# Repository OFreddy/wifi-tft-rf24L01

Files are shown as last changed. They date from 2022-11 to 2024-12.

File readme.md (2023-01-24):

# WifiDisplay

A project for communicating with Hoymiles solar inverters combined with the option to display different values on a 2.4 inch TFT display. 

## Preface
Inspired from the [discussion](https://www.mikrocontroller.net/topic/525778) on (Mikrocontroller.net) I also started investigating on protocol and communication details. With [this](https://www.mikrocontroller.net/topic/525778?page=single#7014857)
 post a first contact to the inverters was the base for several projects.
I wanted an independent display to always have an overview of the current yield data in a simple and clear manner.

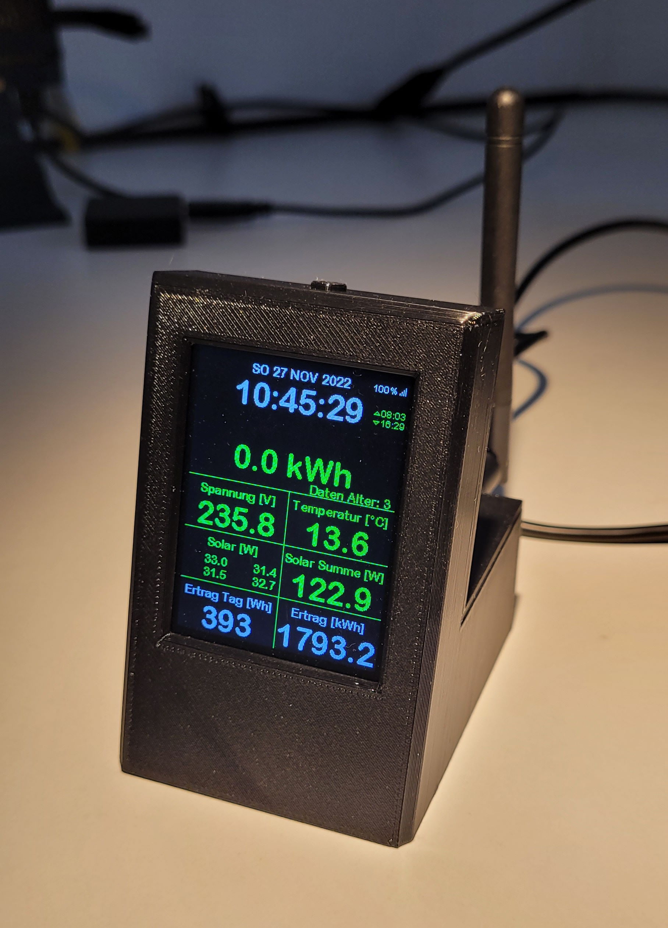
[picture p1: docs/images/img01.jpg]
wifidisplay
   

This project is still a work in progress. It is far away from the almost perfect and comfortable and easy to use solutions from other projects. 

Some more pictures of the latest prototype can be found [here](docs/images/README.md).
---
## Firmware

The firmware for the EPS8266 microcontroller is build with Arduino PlatformIO Framework for the ESP8266. 

It uses a snapshot or a fork of the following projects:

- [ThingPulse minigrafx](https://github.com/ThingPulse/minigrafx)
- [Bounce2](https://github.com/thomasfredericks/Bounce2)
- [RobTillaart CRC](https://github.com/RobTillaart/CRC)
- [BuelowP sunset](https://github.com/buelowp/sunset)

and some more (experimental)...

---
## Hardware - Required components and material 

### ESP8266 WeMos D1 mini

As controller platform a WeMos D1 mini compatible ESP8266 board is required.

Sample picture

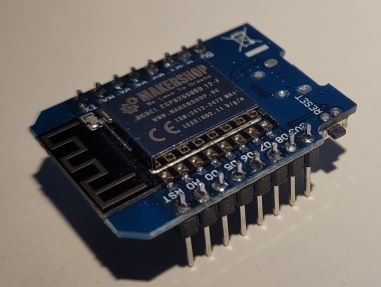
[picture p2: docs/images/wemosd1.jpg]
WeMos-D1 mini


Source of supply
[Makershop](https://www.makershop.de/plattformen/d1-mini/esp8266-mini-board/)
[AZ-Delivery](https://www.az-delivery.de/products/d1-mini)

### NRF24L01+ radio board with external antenna

Sample picture

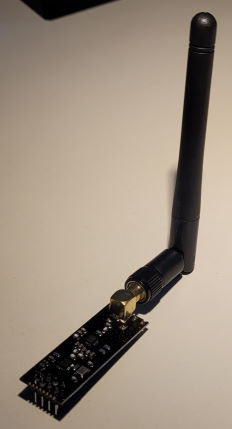
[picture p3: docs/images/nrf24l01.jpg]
NRF24l01


### ILI9341 based TFT Display 320x240 pixel

I always order the TFT modules directly from China via AliExpress. As the suppliers change frequently it is difficult to keep a link updated here. Make sure the pcb has the dimensions 77mm x 42.5mm and a 14 pin header at the bottom for target connection.

**Sample picture**
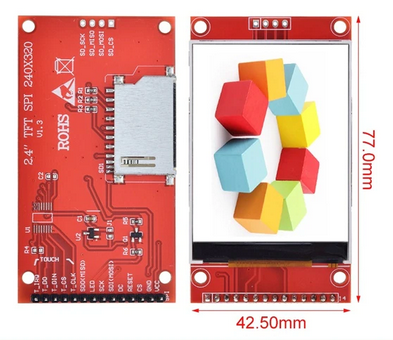
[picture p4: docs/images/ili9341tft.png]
ILI9341 based TFT display


### BOM for the pcb
|Quantity|Item|
|---|----|
|2 pc.|socket strip 8x1 pin 6mm heigth 2.56mm pitch|
|1 pc.|socket strip 4x2 pin 2.56mm pitch|
|1 pc.|socket strip 8x1 pin 8mm height 2.56mm pitch|
|1 pc.|pin header 2x1 pin 2.56mm pitch|
|1 pc.|Polarized capacitor 100uF 35V 2.56mm pitch|
|1 pc.|Capacitor SMD 100nF 0603|
|1 pc.|Resistor SMD 10k 0603|
|1 pc.|Resistor SMD 1k 0603|

### Other components and mounting material

**A tact Button Switch 6 x 6 x 4.3 mm**

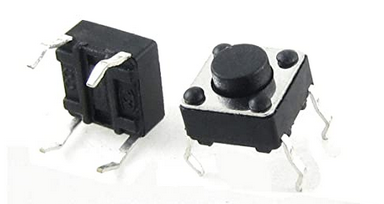
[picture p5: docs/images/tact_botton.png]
Tact botton switch


The switch is used for different options when interacting with the display application. It is mounted inside the housing using the 3D printed mount. The pins of the switch must be bent straight and put through the small holes in the holder as shown on this picture.

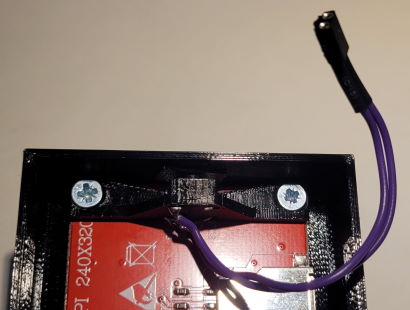
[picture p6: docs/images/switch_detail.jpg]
switch


|Quantity|Item|
|---|----|
|4 pc.|Countersunk screw M3 x 5mm|
|6 pc.|Washer 3.2mm|
|4 pc.|Cylinder head screw M3 x 8mm|
|4 pc.|Nuts M3|

---
## Further documentation

### Connection Summary for ILI9341 TFT Display:

ESP8266       -> ILI9341
Vin           -> Vcc        (red)
GND           -> GND        (black)
GPIO 15  (D8) -> CS         (violett)
GPIO 2   (D4) -> RESET      (brown)
GPIO 4   (D2) -> D/C        (gray)
GPIO 13  (D7) -> SDI(MOSI)  (green)
GPIO 14  (D5) -> SCK        (yellow)
GPIO 5   (D1) -> LED        (orange)
GPIO 12  (D6) -> SDO(MISO)  (spare)

---
## Related Projects
- [OpenDTU](https://github.com/tbnobody/OpenDTU)
- [Ahoy](https://github.com/grindylow/ahoy)
- [DTU Simulator](https://github.com/Ziyatoe/DTUsimMI1x00-Hoymiles)
- [OpenDTU extended to talk to Victrons MPPT battery chargers (Ve.Direct)](https://github.com/helgeerbe/OpenDTU_VeDirect)
- [BreakoutBoard - sample printed circuit board for OpenDTU and Ahoy](https://github.com/dokuhn/openDTU-BreakoutBoard)

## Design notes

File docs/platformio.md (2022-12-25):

# PlatformIO

## Generic boards

Default boards definitionen sind in:
C:\Users\Oliver\.platformio\platforms\espressif8266\boards

Board definition in separates Verzeichnis. Referenzierung dann in Platforio.ini

'board      = esp8266_4M2M'

In der entdprechenden Board.json findet sich der Eintrag:

'"variant": "d1_mini"'

Die Variante referenziert dann die Einstellungen aus:
C:\Users\Oliver\.platformio\packages\framework-arduinoespressif8266\variants

z.B. pins_arduino.h

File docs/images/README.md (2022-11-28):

# Project pictures

Here are some pictures of the project results so far.
***



***

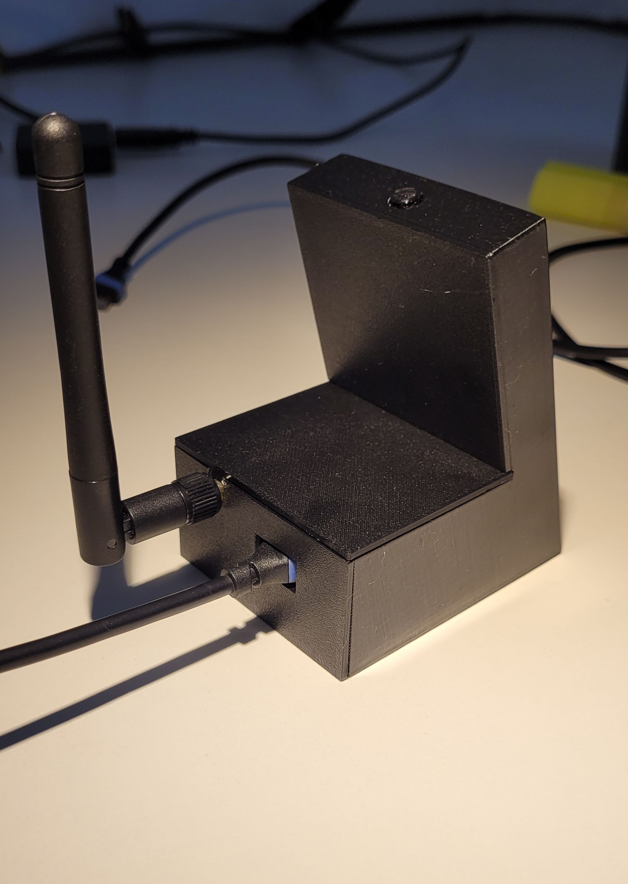
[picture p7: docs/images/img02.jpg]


***

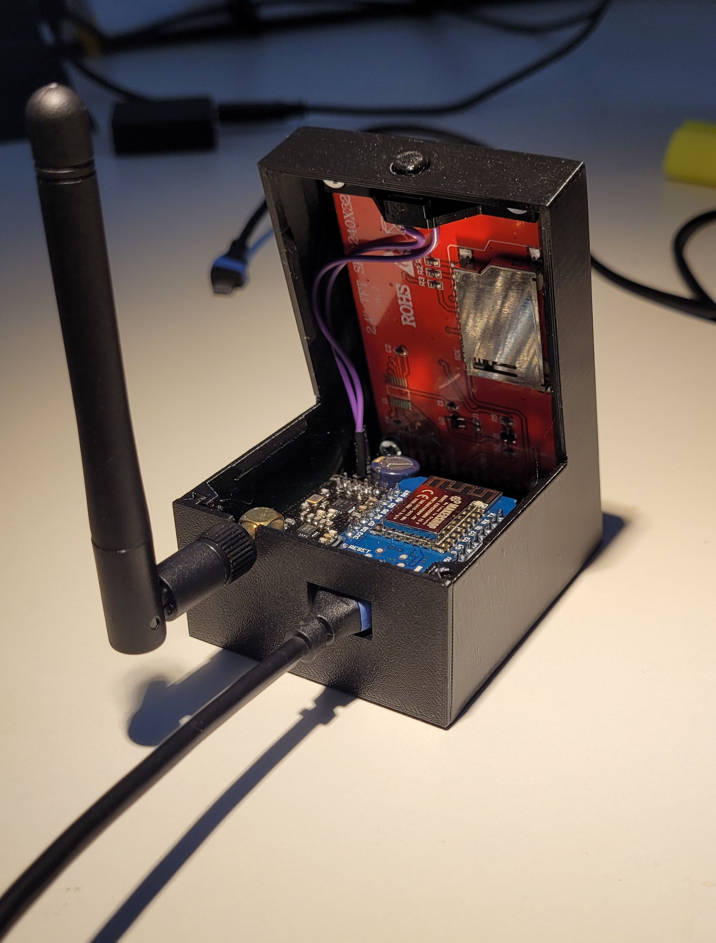
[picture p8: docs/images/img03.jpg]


***

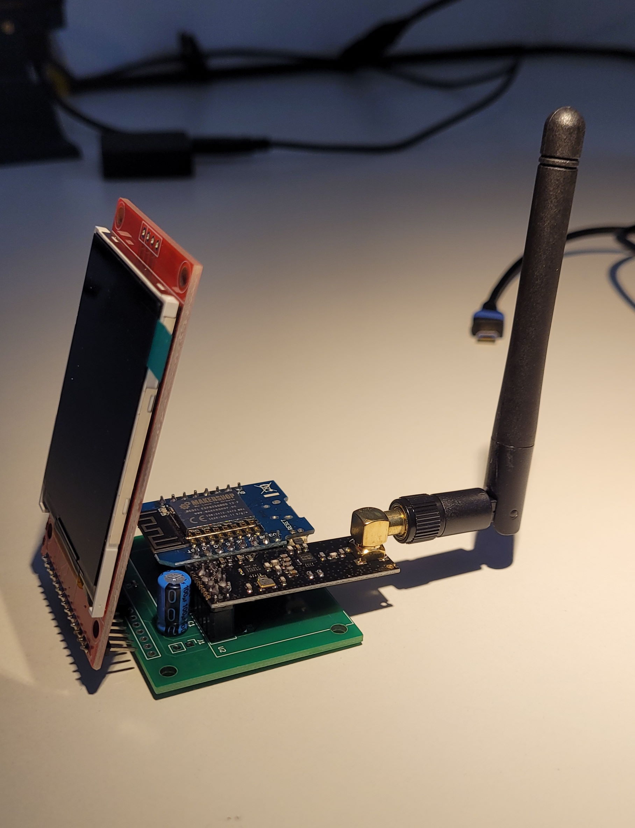
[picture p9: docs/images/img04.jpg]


***

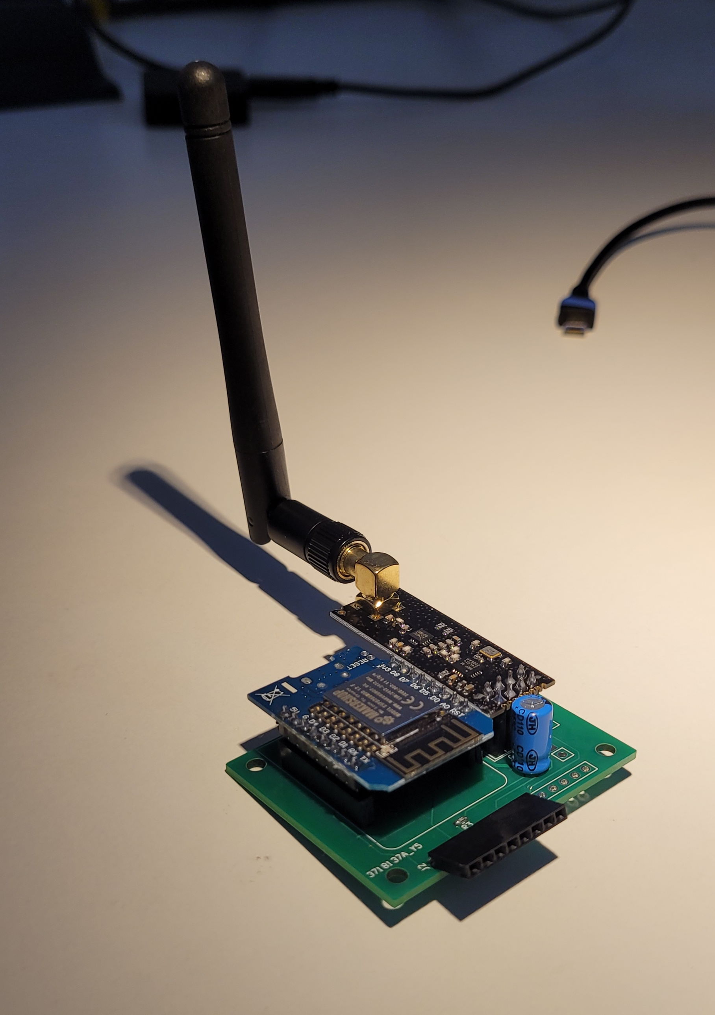
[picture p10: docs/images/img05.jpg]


***

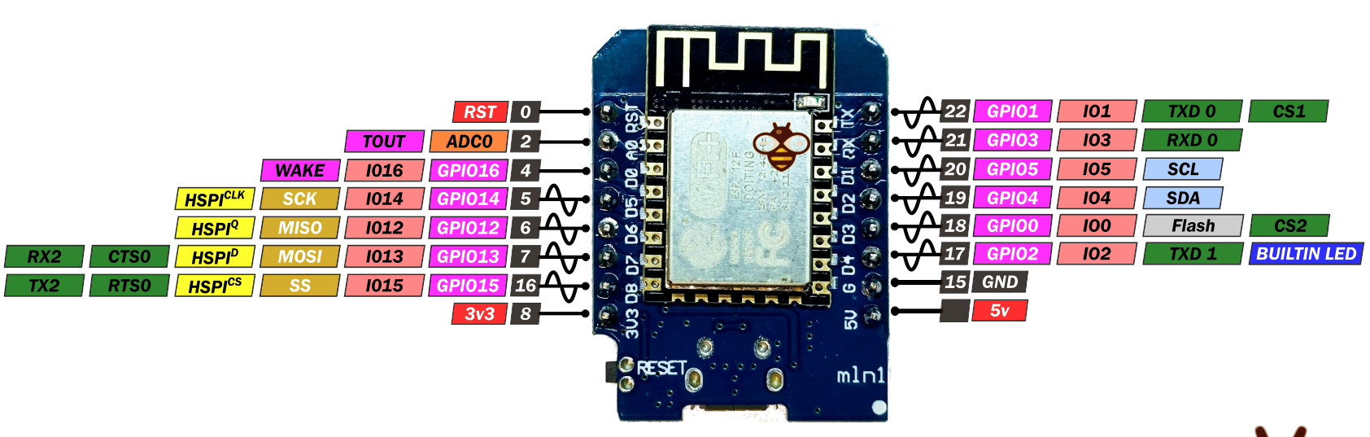
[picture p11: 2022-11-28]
docs/d1_mini_pinout.png

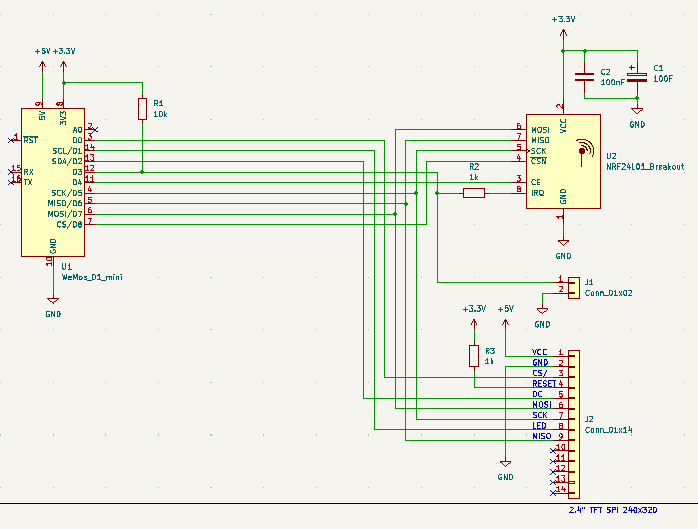
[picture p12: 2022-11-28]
docs/images/schematic.png

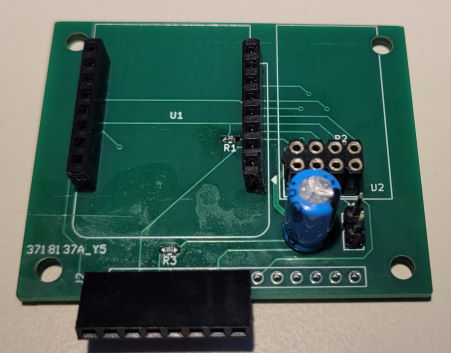
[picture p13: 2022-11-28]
docs/images/pcb_equipped.jpg

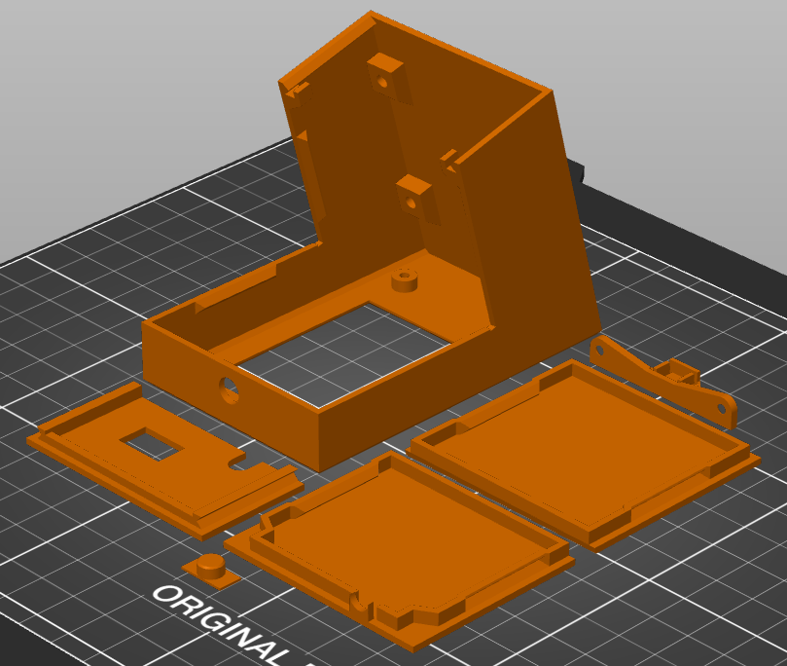
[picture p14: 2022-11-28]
docs/images/prusa slicer project.png

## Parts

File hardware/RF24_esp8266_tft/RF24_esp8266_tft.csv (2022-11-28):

Source: | D:\.workspace\wifidisplay\hardware\RF24_esp8266_tft\RF24_esp8266_tft.kicad_sch
Date: | 27.11.2022 12:58:12
Tool: | Eeschema (6.0.7)
Generator: | C:\Program Files\KiCad\6.0\bin\scripting\plugins/bom_csv_grouped_by_value_with_fp.py
Component Count: | 13
Ref | Qnty | Value | Cmp name | Footprint | Description | Vendor
C1, | 1 | 100uF | C_Polarized | Capacitor_THT:CP_Radial_D5.0mm_P2.50mm | Polarized capacitor
C2, | 1 | 100nF | C | Capacitor_SMD:C_0201_0603Metric_Pad0.64x0.40mm_HandSolder | Unpolarized capacitor
H1, H2, H3, H4, | 4 | MountingHole | MountingHole | MountingHole:MountingHole_3.2mm_M3_DIN965 | Mounting Hole without connection
J1, | 1 | Conn_01x02 | Conn_01x02 | Connector_PinHeader_2.54mm:PinHeader_1x02_P2.54mm_Vertical | Generic connector, single row, 01x02, script generated (kicad-library-utils/schlib/autogen/connector/)
J2, | 1 | Conn_01x14 | Conn_01x14 | Connector_PinHeader_2.54mm:PinHeader_1x14_P2.54mm_Vertical | Generic connector, single row, 01x14, script generated (kicad-library-utils/schlib/autogen/connector/)
R1, | 1 | 10k | R | Resistor_SMD:R_0603_1608Metric_Pad0.98x0.95mm_HandSolder | Resistor
R2, R3, | 2 | 1k | R | Resistor_SMD:R_0603_1608Metric_Pad0.98x0.95mm_HandSolder | Resistor
U1, | 1 | WeMos_D1_mini | WeMos_D1_mini | Module:WEMOS_D1_mini_light | 32-bit microcontroller module with WiFi
U2, | 1 | NRF24L01_Breakout | NRF24L01_Breakout | RF_Module:nRF24L01_Breakout | Ultra low power 2.4GHz RF Transceiver, Carrier PCB

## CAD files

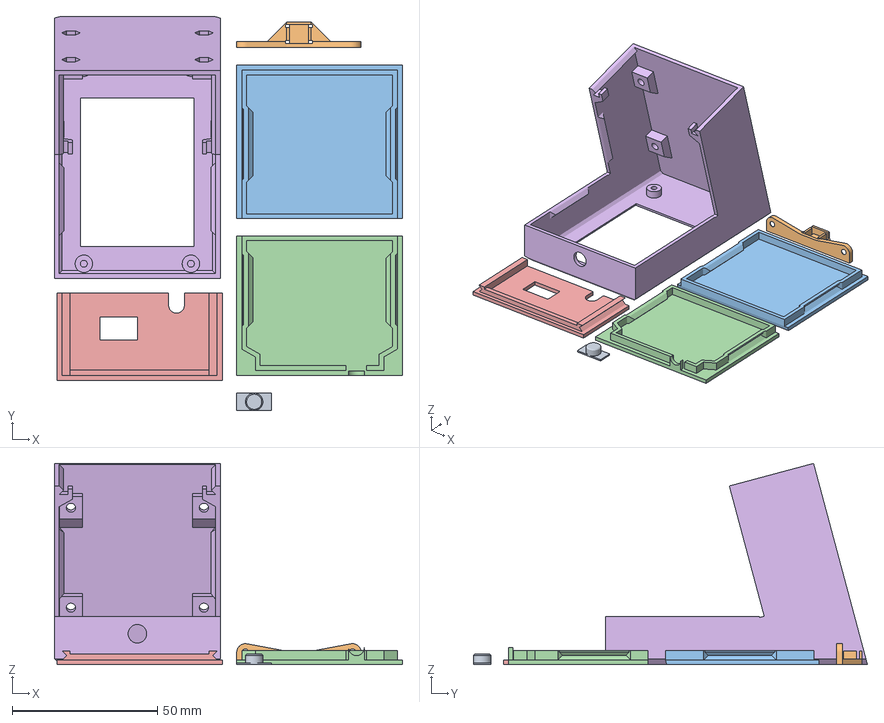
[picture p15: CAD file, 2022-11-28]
hardware/Housing 3d-model/ESP RF2401 TFT Housing complete.3mf
119.6 x 135.4 x 69.2 mm
ESP RF2401 TFT Gehäuse Knopf
ESP RF2401 TFT Gehäuse Taster Halter
ESP RF2401 TFT Gehäuse Deckel
ESP RF2401 TFT Gehäuse hinten oben
ESP RF2401 TFT Gehäuse hinten
ESP RF2401 TFT Gehäuse

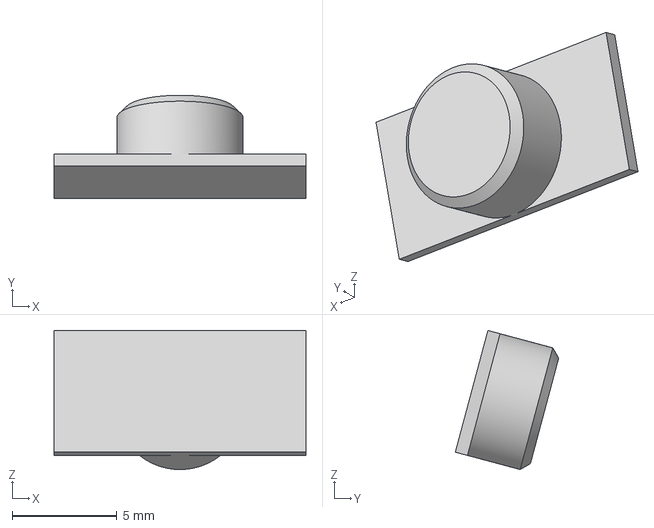
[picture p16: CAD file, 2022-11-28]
hardware/Housing 3d-model/ESP RF2401 TFT Housing knob.3mf
12.0 x 4.93 x 6.62 mm

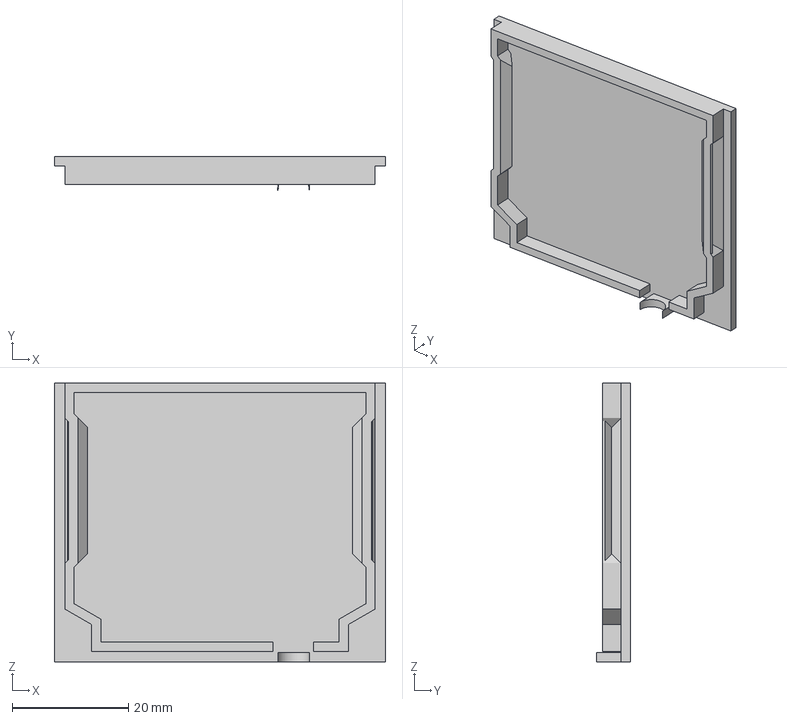
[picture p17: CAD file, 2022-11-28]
hardware/Housing 3d-model/ESP RF2401 TFT Housing back top.3mf
57.0 x 5.79 x 48.0 mm

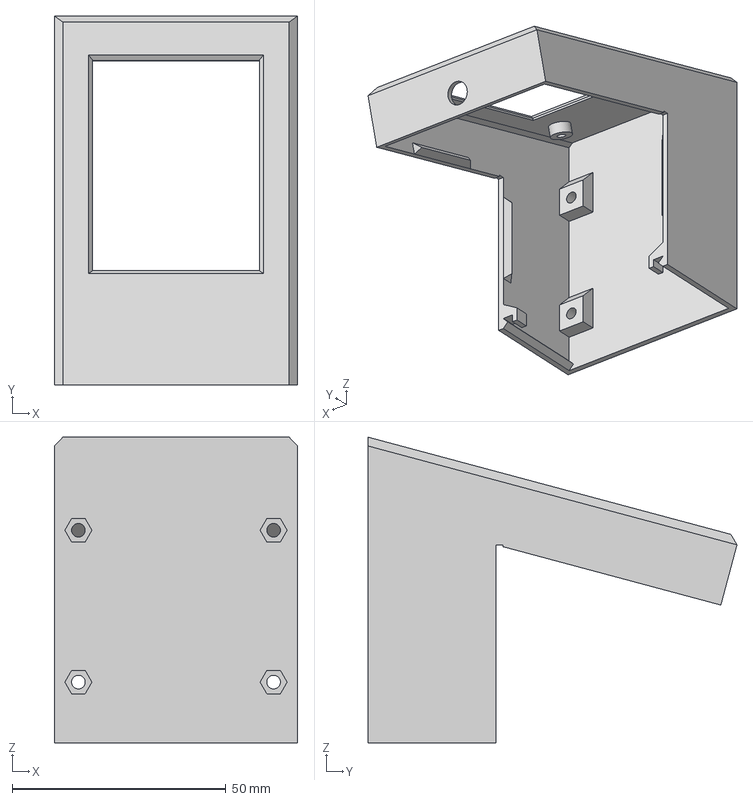
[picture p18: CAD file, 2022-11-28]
hardware/Housing 3d-model/ESP RF2401 TFT Housing.3mf
57.0 x 86.4 x 71.6 mm

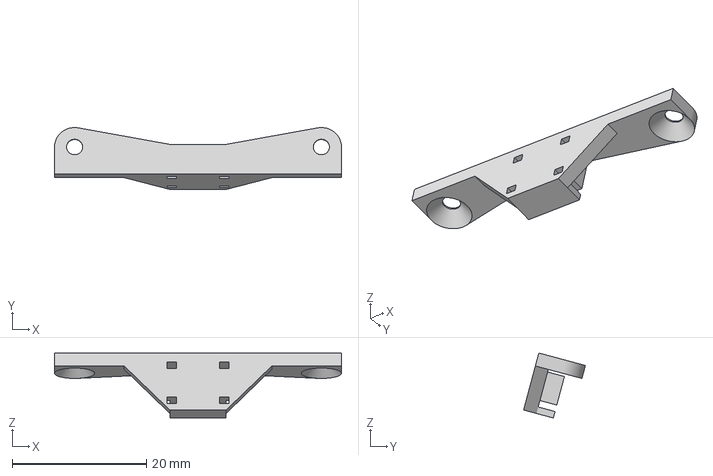
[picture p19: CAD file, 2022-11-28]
hardware/Housing 3d-model/ESP RF2401 TFT Housing switch support.3mf
42.8 x 9.23 x 9.69 mm

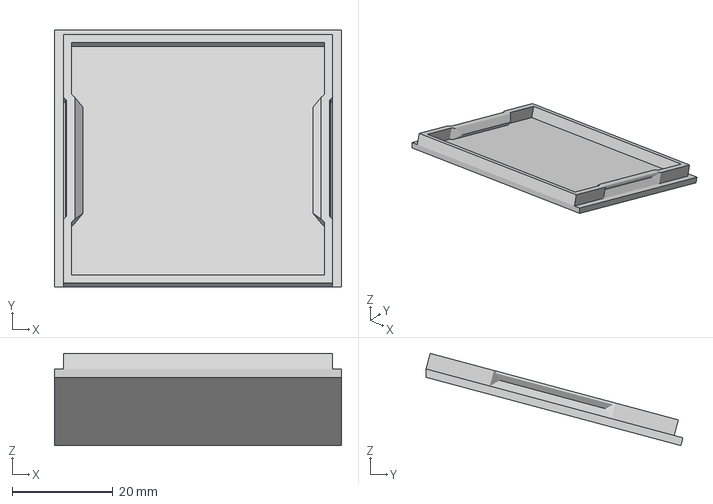
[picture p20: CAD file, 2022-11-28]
hardware/Housing 3d-model/ESP RF2401 TFT Housing Top.3mf
57.0 x 51.0 x 18.3 mm

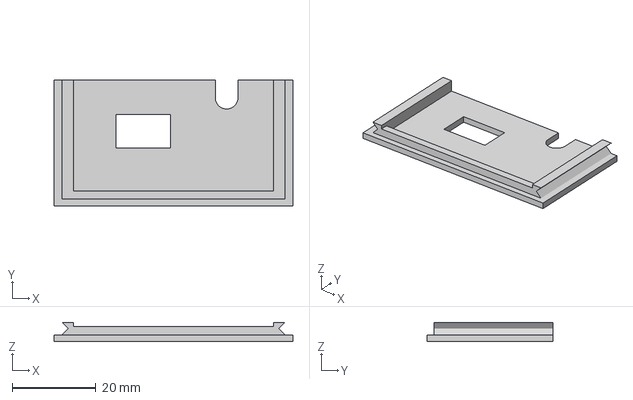
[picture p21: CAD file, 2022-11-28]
hardware/Housing 3d-model/ESP RF2401 TFT Housing back.3mf
57.0 x 30.0 x 4.60 mm

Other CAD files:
hardware/Housing 3d-model/ESP RF2401 TFT Housing.f3d

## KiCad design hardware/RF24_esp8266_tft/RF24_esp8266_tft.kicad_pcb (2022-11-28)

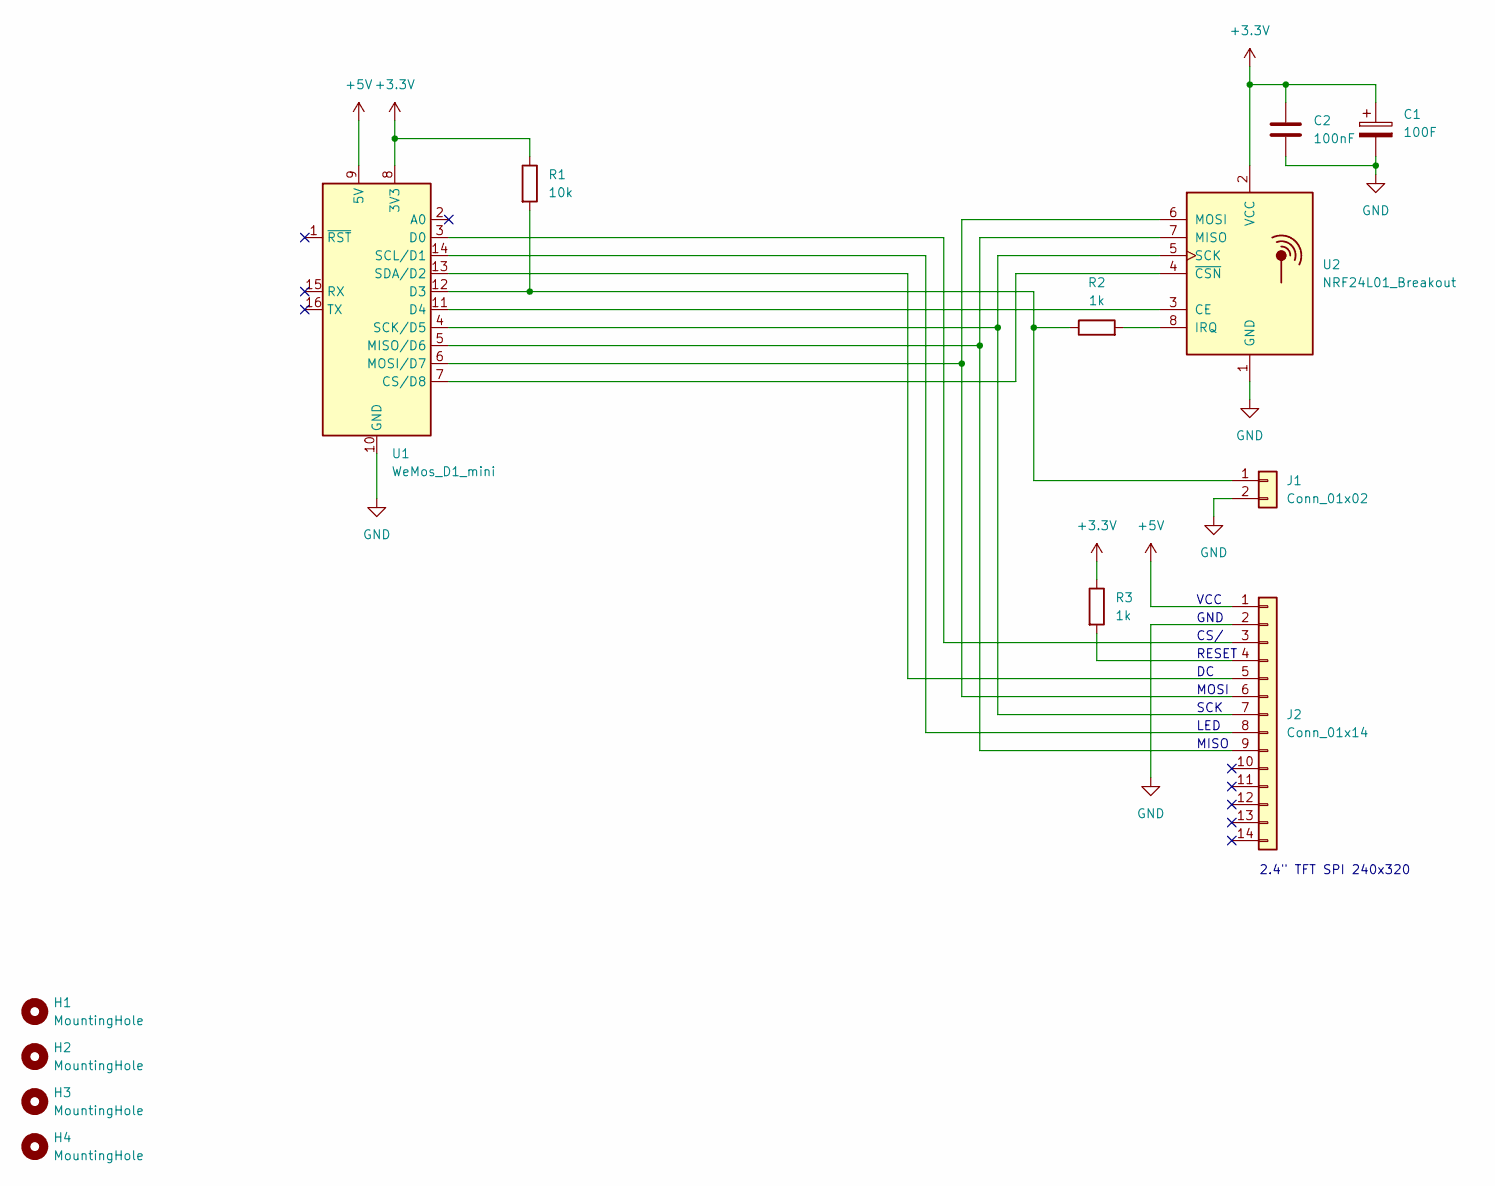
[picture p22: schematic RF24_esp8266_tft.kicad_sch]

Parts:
C1: 100F; CP_Radial_D5.0mm_P2.50mm
C2: 100nF; C_0201_0603Metric_Pad0.64x0.40mm_HandSolder
H1, H2, H3, H4: MountingHole; MountingHole_3.2mm_M3_DIN965
J1: Conn_01x02; PinHeader_1x02_P2.54mm_Vertical
J2: Conn_01x14; PinHeader_1x14_P2.54mm_Vertical
R1: 10k; R_0603_1608Metric_Pad0.98x0.95mm_HandSolder
R2, R3: 1k; R_0603_1608Metric_Pad0.98x0.95mm_HandSolder
U1: WeMos_D1_mini; WEMOS_D1_mini_light
U2: NRF24L01_Breakout; nRF24L01_Breakout

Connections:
+3.3V: C1.1, C2.1, R1.1, R3.1, U1.8 (3V3), U2.2 (VCC)
+5V: J2.1, U1.9 (5V)
GND: C1.2, C2.2, J1.2, J2.2, U1.10 (GND), U2.1 (GND)
unnamed: J1.1, R1.2, R2.1, U1.12 (D3)
unnamed: J2.3, U1.3 (D0)
unnamed: J2.4, R3.2
unnamed: J2.5, U1.13 (SDA/D2)
unnamed: J2.6, U1.6 (MOSI/D7), U2.6 (MOSI)
unnamed: J2.7, U1.4 (SCK/D5), U2.5 (SCK)
unnamed: J2.8, U1.14 (SCL/D1)
unnamed: J2.9, U1.5 (MISO/D6), U2.7 (MISO)
unnamed: R2.2, U2.8 (IRQ)
unnamed: U1.7 (CS/D8), U2.4 (~CSN)
unnamed: U1.11 (D4), U2.3 (CE)

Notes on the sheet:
CS/
2.4" TFT SPI 240x320
VCC
MOSI
SCK
RESET
MISO
LED
GND

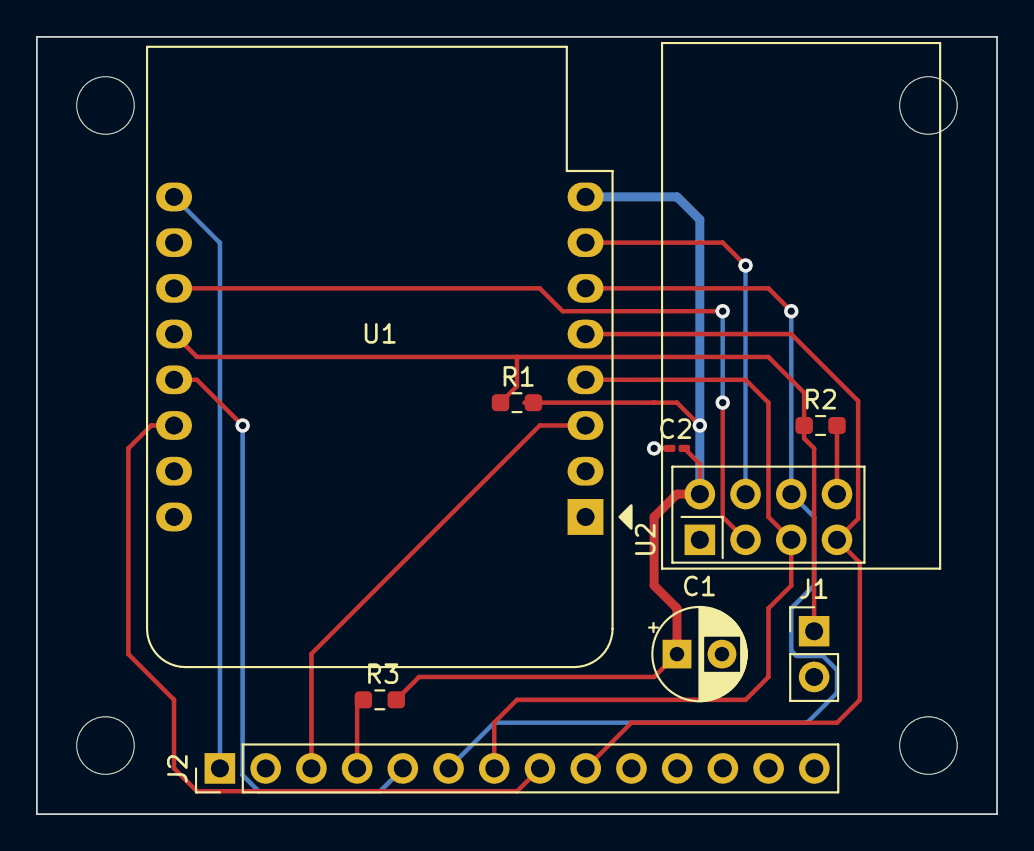
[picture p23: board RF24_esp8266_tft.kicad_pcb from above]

Board: 2 copper layers, 53.3 x 43.2 mm, 13 parts (0 on the bottom side), 14 nets.

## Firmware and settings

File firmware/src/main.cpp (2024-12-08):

#include "Arduino.h"

// Applicatiom
#include "app.h"

app myApp;

#if defined(NUMBER_OF_INVERTERS) && (NUMBER_OF_INVERTERS > 0)
// RF24 Radio
#include <SPI.h>
#include <CircularBuffer.h>
#include <RF24.h>
#include <RF24_config.h>
#include "peripherals.h"
#include "hm_crc.h"
#include "hm_radio.h"

static RF24 radio(RF1_CE_PIN, RF1_CS_PIN);
// Hoymiles packets instance
HM_Radio hmRadio(&radio);

static IRAM_ATTR void handleNrf1Irq()
{
	hmRadio.RadioIrqCallback();
}

static void DumpConfig()
{
	Serial.println(F("\nRadio:"));
	radio.printDetails();

	Serial.println("");
}

static void activateConf(void)
{
	// Attach interrupt handler to NRF IRQ output. Overwrites any earlier handler.
	attachInterrupt(digitalPinToInterrupt(RF1_IRQ_PIN), handleNrf1Irq, FALLING); // NRF24 Irq pin is active low.

	DumpConfig();
}
#endif

//-----------------------------------------------------------------------------

static void DumpMenu()
{
	Serial.println("Console menu");
	Serial.println("============\n");
#if defined(NUMBER_OF_INVERTERS) && (NUMBER_OF_INVERTERS > 0)
	Serial.println("c = Print RF24 module config");
#endif
	Serial.println("r = Reset module");
#if defined(NUMBER_OF_INVERTERS) && (NUMBER_OF_INVERTERS > 0)
	Serial.println("t = Toggle RF24 traffic debug output");
#endif	
}

//-----------------------------------------------------------------------------
void setup()
{
	Serial.begin(SERIAL_BAUDRATE);
	Serial.println(F("\n\n------------------------------------------\nWifiDisplay starting...\n"));

	myApp.setup();

#if defined(NUMBER_OF_INVERTERS) && (NUMBER_OF_INVERTERS > 0)
	// Configure nRF IRQ input
	pinMode(RF1_IRQ_PIN, INPUT);

	// Add inverter instances - check HM_MAXINVERTERINSTANCES in hm_config.h
	bool res = hmRadio.AddInverterInstance(INV1_SERIAL);
#if (NUMBER_OF_INVERTERS > 1)
	res = hmRadio.AddInverterInstance(INV2_SERIAL);
#if (NUMBER_OF_INVERTERS > 2)
	res = hmRadio.AddInverterInstance(INV3_SERIAL);
#if (NUMBER_OF_INVERTERS > 3)
	res = hmRadio.AddInverterInstance(INV4_SERIAL);
#endif
#endif
#endif
	if (!res)
	{
		Serial.println(F("Failed to add inverter instances!"));
		while (1)
			;
	}
	if (!hmRadio.Begin())
	{
		Serial.println(F("Failed to start up radio!\n"));
		while (1)
			;
	}
	activateConf();
#endif
}

//-----------------------------------------------------------------------------
void loop()
{
	static bool bHMTransmitting = false;
#if defined(NUMBER_OF_INVERTERS) && (NUMBER_OF_INVERTERS > 0)
	static bool bDumpRFData = false;
#endif

	myApp.loop(bHMTransmitting);

#if defined(NUMBER_OF_INVERTERS) && (NUMBER_OF_INVERTERS > 0)
	// Cyclic communication processing
	hmRadio.SetUnixTimeStamp(myApp.getUnixTimeStamp());
	bHMTransmitting = hmRadio.Cyclic();
#endif

	// Config info
	if (Serial.available())
	{
		uint8_t cmd = Serial.read();

		if (cmd == '?')
		{
			DumpMenu();
		}
#if defined(NUMBER_OF_INVERTERS) && (NUMBER_OF_INVERTERS > 0)
		else if (cmd == 'c')
		{
			DumpConfig();
		}
#endif
		else if (cmd == 'r')
		{
			DBG_PRINTF(DBG_PSTR("Resetting..."));
			delay(200);
			ESP.reset();
		}
#if defined(NUMBER_OF_INVERTERS) && (NUMBER_OF_INVERTERS > 0)
		else if (cmd == 't')
		{
			bDumpRFData = !bDumpRFData;
			hmRadio.DumpRFData(bDumpRFData);
		}
#endif
	}
}

///////////////////////////////////////////////////////////////////////////////////////////////////////////////////////
/// End of file
///////////////////////////////////////////////////////////////////////////////////////////////////////////////////////

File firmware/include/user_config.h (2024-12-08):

/*
 Copyright (C)
    2022            OFreddy

 This program is free software; you can redistribute it and/or
 modify it under the terms of the GNU General Public License
 version 3 as published by the Free Software Foundation.
*/

#pragma once

/*****************************************************************************************************\
 * USAGE:
 *   To modify the stock configuration according to your personal settings:
 *   (1) copy this file to "user_config_override.h" (It will be ignored by Git)
 *   (2) define your own settings in "user_config_override.h"
 *
\*****************************************************************************************************/

#define SERIAL_BAUDRATE   115200 // UART Debuggging console baudrate

#define CFG_MGCNUMBER     0x2225 // Change this value to load SECTION1 configuration parameters to flash
#define CGF_VERSION       0x0101 // Configuration set version

#define WIFI_AP_ACTIVE_TIME   60 // Period for which ESP will remain in AP mode in case of STA connect error

#define WIFI_SOFT_AP_CHANNEL   1 // Soft Access Point Channel number between 1 and 13 

#define WIFI_SOFT_AP_DNS_PORT 53 // Soft Access Point DNS port number

// Access Point Info
// In case there is no WiFi Network or Ahoy can not connect to it, it will act as an Access Point

#define WIFI_AP_SSID      "WiFiTFT24"
#define WIFI_AP_PWD       "wifitft24"

#define APP_HOSTNAME      "WiFiTFT-%06X"

#define STA_SSID1         "YourSSID1"         
#define STA_PASS1         "YourWifiPassword1"     

#define STA_SSID2         "YourSSID2"         
#define STA_PASS2         "YourWifiPassword2"     

#define TIMESERVER_NAME   "pool.ntp.org"
#define TIMESERVER_PORT   123

#define NTP_TIMEZONEDESCR "Europe/Amsterdam"

#define SUNSET_ENABLED    true      // Enables sunset calculation

#define SUNSET_LATITUDE   "50.941291" // Latitude - Your location to be used with sunrise and sunset
#define SUNSET_LONGITUDE  "6.95828" // Longitude - Your location to be used with sunrise and sunset

#define SUNSET_SUNRISEOFFSET -15    // Offset in minutes to be addded to calculated sunrise time
#define SUNSET_SUNSETOFFSET 15      // Offset in minutes to be addded to calculated sunset time

#define NUMBER_OF_INVERTERS 1       // Amount of Hoymiles inverters to be processed
#define INV1_SERIAL ((uint64_t)0x116181542101ULL)  // 116181542101 = Inverter serial number

#define HTTP_REQUEST_INTERVALL 2000 // Http Request intervall for requesting data from HTTP source

#define HTTP_RESPONSE_TIMEOUT 30000 // HTTP Response timeout to indicate missing responses


#if __has_include("user_config_override.h")
  #include "user_config_override.h"              // Configuration overrides for my_user_config.h
#endif

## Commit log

2023-01-24 Cleanup / Added revised model for Housing
    Bugfix SunsetClass
    Moved library minigrafx to custom fork
    [ESP RF2401 TFT Housing Top.3mf, ESP RF2401 TFT Housing back top.3mf, ESP RF2401 TFT Housing back.3mf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]
2024-12-08 Updated ENV_STR to new powermeter
